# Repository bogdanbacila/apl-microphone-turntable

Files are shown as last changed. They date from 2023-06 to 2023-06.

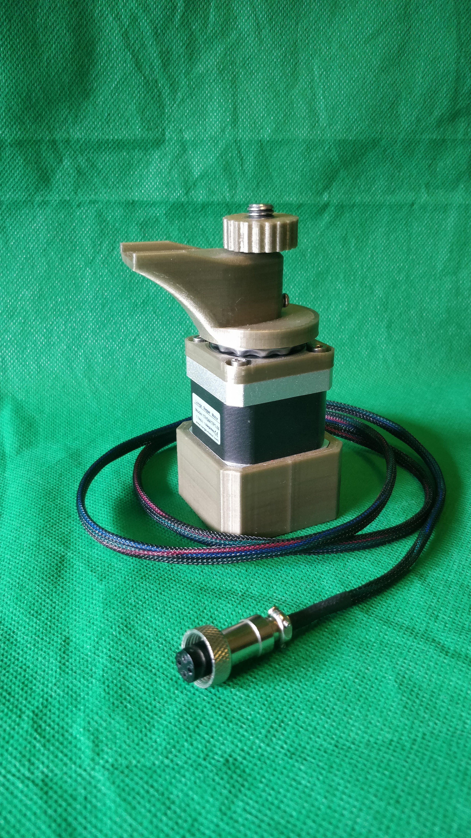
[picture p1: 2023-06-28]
photos/IMG_20200703_163624.jpg

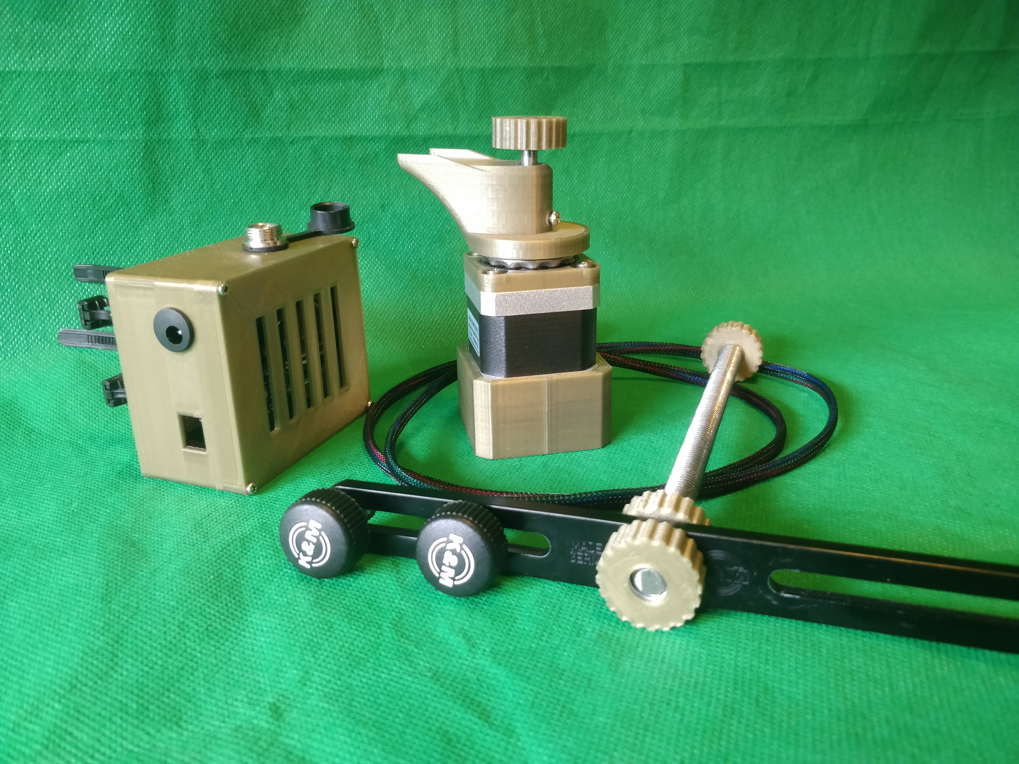
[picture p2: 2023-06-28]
photos/IMG_20200703_164254.jpg

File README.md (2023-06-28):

# microphone-turntable

*Screenshots of the connection and control process are available in the “Screenshots folder”
*Pictures of the connected device and possible mounting configurations are available in the “Photos” folder
*The Matlab library in in the “Matlab” folder
*The Arduino script used for controlling the motor is in the “Arduino” folder

Powering the device:

- Connect the motor cable to the controller box and fasten the screw.
!!IMPORTANT!! Do not power on the device without connecting the motor cable to the controller box.
- Plug in the power supply to the controller box. 

Connecting to the device:

- Go to System preferences -> Bluetooth.
- Find the “APLMicTurntable” device and click Connect.
- The device might not connect from the first try, click on Options, and change the passcode to “1234” and click Connect.
- Now the device should appear as connected.

Controlling the device:

- Open Matlab (required > R2019b)
- Make sure the working folder has the “APLMicTurntable.m” library on the same level
- use the “serialportlist” command to check the available serial ports. You are looking for the “/dev/cu.APLMicTurntable-DevB” port. 
- Create an instance of the APL Mic Turntable. The first variable in the constructor is the serial port you have to connect to and the second variable is the baud rate (this has to be 9600)

Example:

turntable = APLMicTurntable("/dev/cu.APLMicTurntable-DevB", 9600)

- Once the object is instantiated you can now try rotating the motor. The APLMicTurntable.rotate(angle) allows you to do so. You can use integer and floating point values for rotating to a specific angle. 

Example:

turntable.rotate(5) %rotates 5 degrees clockwise
turntable.rotate(-5) %rotates 5 degrees counter-clockwise 
turntable.rotate(2.5) %rotates 2.5 degrees clockwise
turntable.rotate(-2.5) %rotates 2.5 degrees counter-clockwise

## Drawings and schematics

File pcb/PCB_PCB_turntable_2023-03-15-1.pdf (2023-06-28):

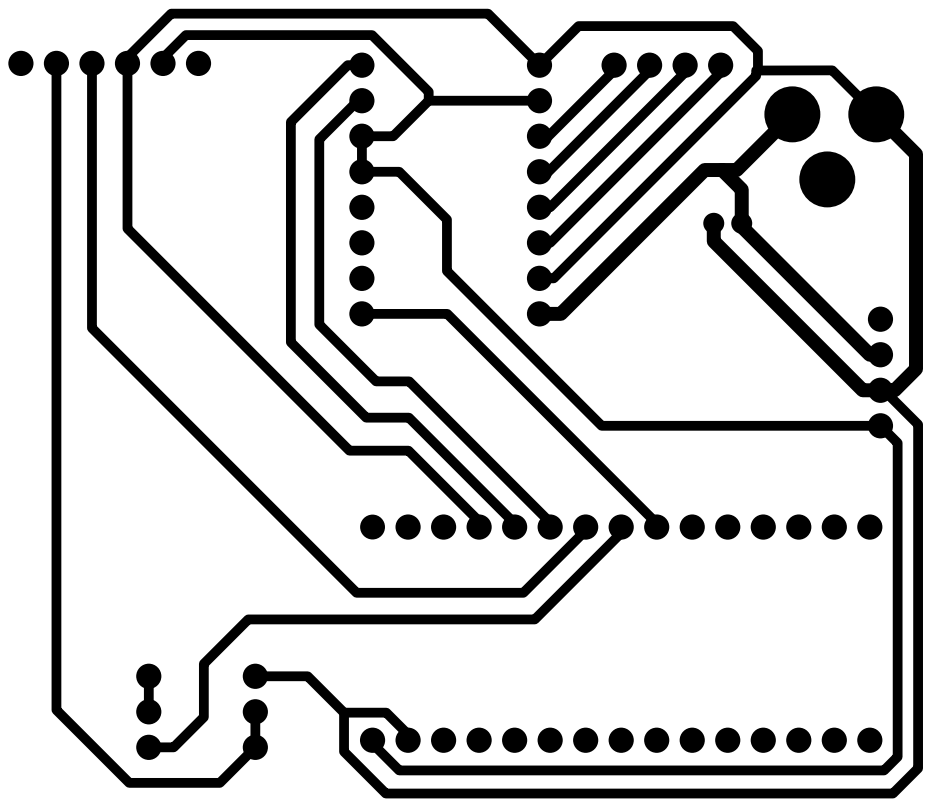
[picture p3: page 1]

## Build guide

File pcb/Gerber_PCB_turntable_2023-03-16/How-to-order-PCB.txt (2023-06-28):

How to Order PCB

Please refer to:
https://docs.easyeda.com/en/PCB/Order-PCB

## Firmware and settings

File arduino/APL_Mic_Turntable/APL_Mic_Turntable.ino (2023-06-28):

#include <Arduino.h>
#include <SoftwareSerial.h>

// Handy resorurce for fixing high-pitch- whine on counterfeit DRV8825: https://softsolder.com/2019/08/23/drv8825-stepper-driver-forcing-fast-decay-mode-in-a-likely-counterfeit-chip/

// You need to have the StepperDriver library installed
// Tools -> Manage Libraries -> Search for "stepperDriver"
// Make sure the author is "Laurentiu Badea" 
// Version number: 1.3.1
// Alternatively, this is the library repo: https://github.com/laurb9/StepperDriver
#include "BasicStepperDriver.h"

// Motor steps per revolution. Most steppers are 200 steps or 1.8 degrees/step
#define MOTOR_STEPS 200
#define RPM 5

// Since microstepping is set externally, make sure this matches the selected mode on your stepper driver
// If it doesn't, the motor will move at a different RPM than chosen
// 1=full step, 2=half step, 4=quarter step, etc.
#define MICROSTEPS 16

// digital outputs connecting to the stepper driver. 
#define DIR_PIN 2
#define STEP_PIN 3

// 2-wire basic config, microstepping is hardwired on the driver
BasicStepperDriver stepper(MOTOR_STEPS, DIR_PIN, STEP_PIN);

// Connect the Arduino RX on pin 4 to the HC-06 TX.
// Connect the Arduino TX on pin 5 to the HC-06 RX through a voltage divider.
SoftwareSerial BTserial(4,5); // RX | TX

//declare variables
String inString = "";
float angle;
bool sendFlag = false;

void setup() {
  BTserial.begin(9600);
  stepper.begin(RPM, MICROSTEPS);
  // if using enable/disable on ENABLE pin (active LOW) instead of SLEEP uncomment next line
  // stepper.setEnableActiveState(LOW);
}

void loop() {

  while (BTserial.available() > 0) {
    int inChar = BTserial.read();

    if (inChar != '\n') {

      // As long as the incoming byte
      // is not a newline,
      // convert the incoming byte to a char
      // and add it to the string
      inString += (char)inChar;
    }
    // if you get a newline, print the string,
    // then the string's value as a float:
    else {
      angle = inString.toFloat();
      sendFlag = true;
      inString = "";
    }
  }

  //rotate motor to the desired angle and direction
  if (sendFlag){  
    stepper.rotate(angle);
    sendFlag = false;
    delay(1000); 
  }
        
}
